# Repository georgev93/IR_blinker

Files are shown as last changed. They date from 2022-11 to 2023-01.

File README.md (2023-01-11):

# IR Blinker

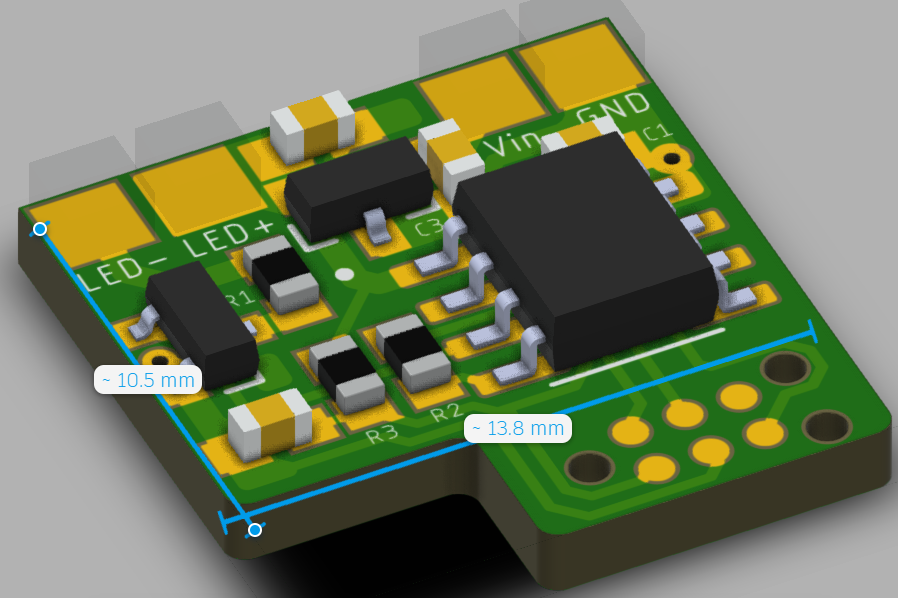
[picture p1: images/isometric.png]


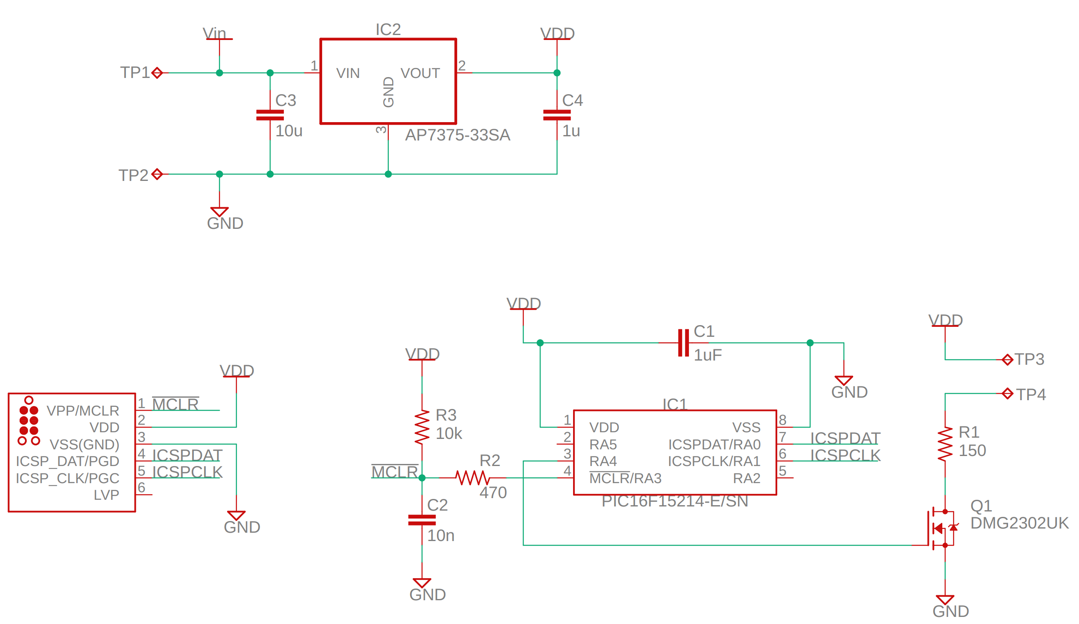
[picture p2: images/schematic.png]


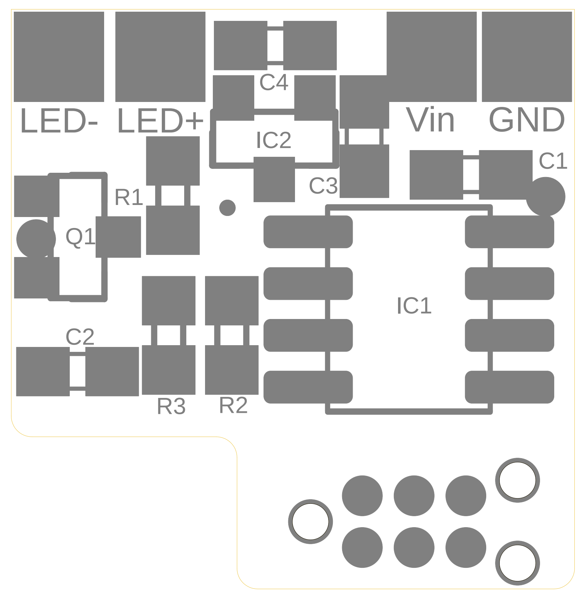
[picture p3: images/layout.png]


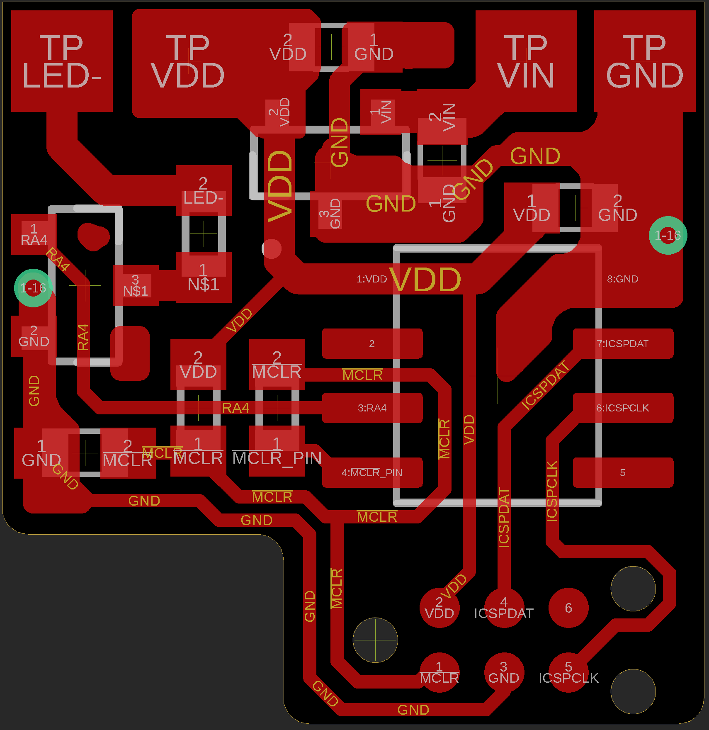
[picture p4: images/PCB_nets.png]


## Programming Connection

The programming tab shown at the bottom of the rendering above (which can be cut off after flashing for minimal final board size!) can be connected to a PIC programmer (such as a PICkit or ICD) via a Tag-Connect cable. The Tag-Connect cable should be a 6-pin no-legs variant such as [this one](https://www.tag-connect.com/product/tc2030-pkt-nl-6-pin-no-legs-cable-for-microchip-pickit-3) that connects to a [PICkit 3](https://www.microchip.com/en-us/development-tool/pg164130). A [retention clip](https://www.tag-connect.com/product/tc2030-retaining-clip-board-3-pack) for the no-leg Tag-connect connector makes life very easy. Lastly, if you lose your retention clips, you might want to invest in a [state-of-the-art-and-absolutely-not-just-a-paperclip retention clip holder](https://www.tag-connect.com/product/tc20x0-cliphanger).

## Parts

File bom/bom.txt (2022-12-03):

Part     Value            Package       Digikey P/N                     Mouser P/N

C1, C4   1uF              C0603         587-3305-1-ND                   963-EMK107B7105KAHT          
C2       10n              C0603         445-1311-1-ND                   810-C1608X7R1H103K
C3       10u              C0603         490-18214-1-ND                  81-GRM188R61E106KA3D
IC1      PIC16F15214-E/SN SOIC-8        150-PIC16F15214-I/SN-ND         (Out of stock)
IC2      AP7375-33SA      SOT23         (Out of stock)                  AP7375-33SA-7
Q1       DMG2302UK        SOT23         DMG2302UK-7DICT-ND              621-DMG2302UK-7
R1       150              R0603         13-RC0603FR-13150RLCT-ND        603-RC0603FR-13150RL
R2       470              R0603         13-RC0603FR-10470RLCT-ND        603-RC0603FR-10470RL
R3       10k              R0603         13-RC0603FR-1310KLCT-ND         603-RC0603FR-1310KL

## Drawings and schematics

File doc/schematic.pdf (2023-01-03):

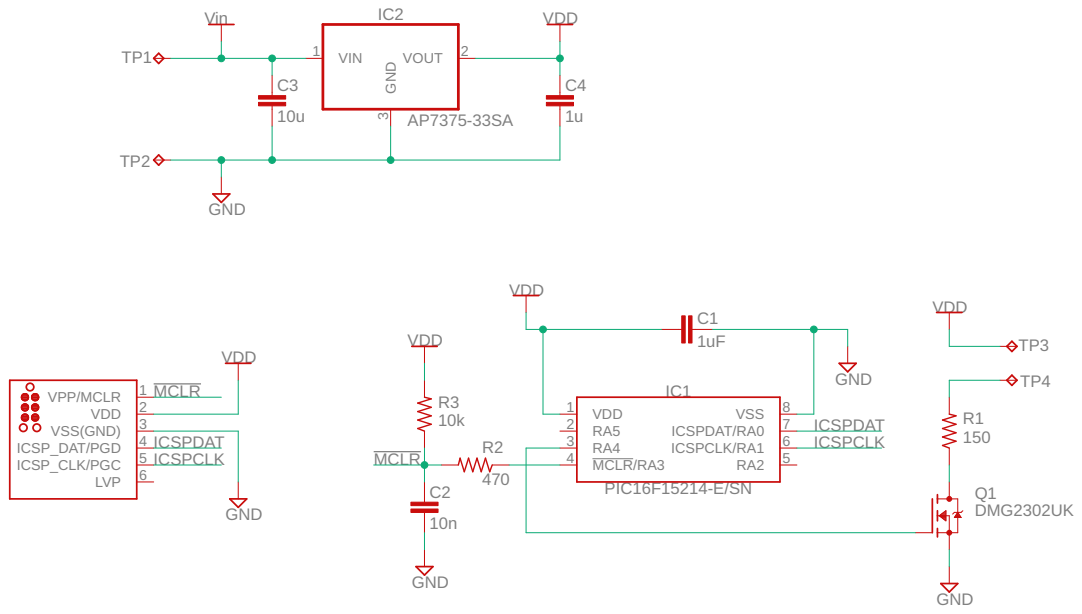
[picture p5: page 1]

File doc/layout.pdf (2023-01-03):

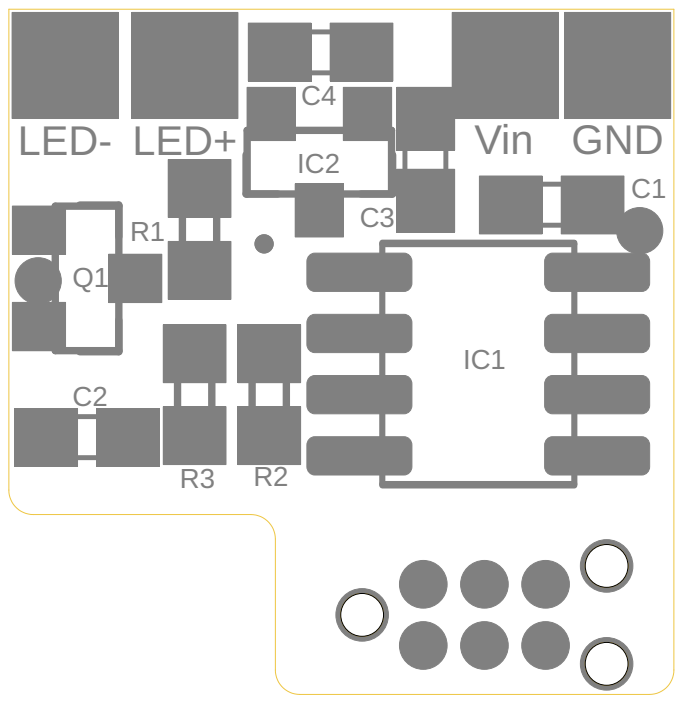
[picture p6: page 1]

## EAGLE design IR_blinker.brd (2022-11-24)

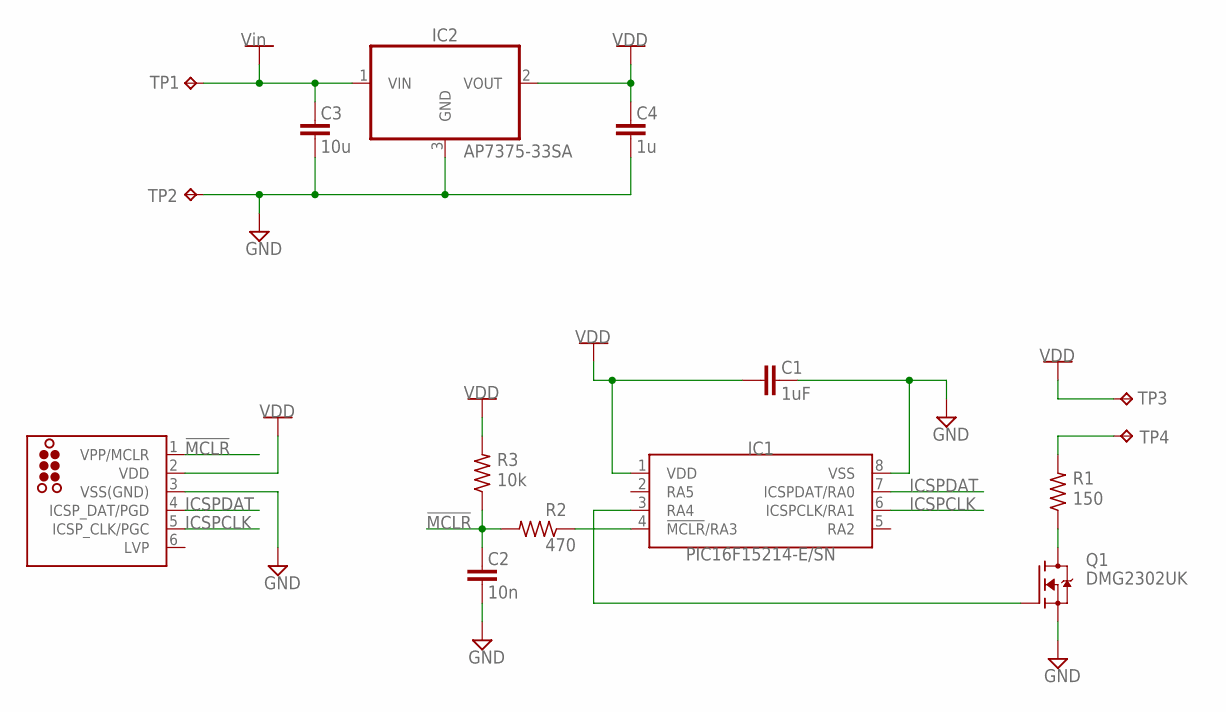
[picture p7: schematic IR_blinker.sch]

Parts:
C1: 1uF; C0603
C2: 10n; C0603
C3: 10u; C0603
C4: 1u; C0603
IC1: PIC16F15214-E/SN; SOIC-8
IC2: AP7375-33SA; SOT23
J1: TC2030-MCP-NL
Q1: DMG2302UK; SOT23
R1: 150; R0603
R2: 470; R0603
R3: 10k; R0603
TP1, TP2, TP3, TP4: TPTP20SQ; TP20SQ

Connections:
!MCLR: C2.2, J1.1 (VPP/MCLR), R2.2, R3.1
GND: C1.2, C2.1, C3.1, C4.1, IC1.8 (VSS), IC2.3 (GND), J1.3 (VSS(GND)), Q1.2 (S), TP2.TP
ICSPCLK: IC1.6 (ICSPCLK/RA1), J1.5 (ICSP_CLK/PGC)
ICSPDAT: IC1.7 (ICSPDAT/RA0), J1.4 (ICSP_DAT/PGD)
LED_RETURN: R1.2, TP4.TP
unnamed: Q1.3 (D), R1.1
unnamed: IC1.3 (RA4), Q1.1 (G)
unnamed: IC1.4 (!MCLR!/RA3), R2.1
VDD: C1.1, C4.2, IC1.1 (VDD), IC2.2 (VOUT), J1.2 (VDD), R3.2, TP3.TP
VIN: C3.2, IC2.1 (VIN), TP1.TP

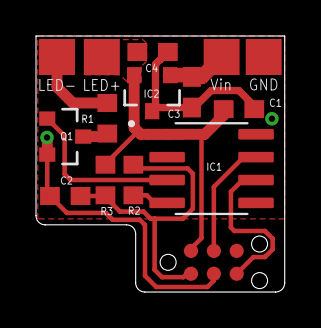
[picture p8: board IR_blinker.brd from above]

Board: 2 copper layers, 13.8 x 14.2 mm, 15 parts (0 on the bottom side), 10 nets.

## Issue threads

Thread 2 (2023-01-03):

Setting the current for the IR LED

georgev93, 2023-01-03:
So @emailing-files-is-still-better, not knowing what IR LED you're using for this bad boy I wasn't able to exactly dial in the current we want. Therefore, R1 is at 150 Ohms, which works well for a surface mount LED I picked out before I switched it to an off-board IR LED. Once you know your IR LED, you'll want to set the current appropriately (although 150 ohms might do you just fine).

### Step 1: Pick luminosity

If you have the datasheet, there should be a graph that correlates current to luminosity (or radiant intensity, lux, brightness, etc.). Like this one for the [TSAL6100](https://components101.com/sites/default/files/component_datasheet/IR%20LED%20datasheet.pdf):

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

(Note the nearly linear relationship between log(current) and log(radiant intensity))

Pick your value. Better yet, if you have a lab power supply, drive a constant current through the LED, then pick your favorite luminosity. You can set a power supply in "constant current" mode by setting your limit to something like 10mA, then set your voltage to something that is higher than what you expect the forward voltage drop to be (like 5V). When you connect the LED to the power supply, it will only let 10mA through, so it will drop the voltage until it achieves that current (constant current mode).

 One way or another, this value determines the current that we want to run through the LED. You can likely use your phone camera to compare brightness of LEDs (although if you're comparing to a 50% duty cycle LED, it'll show up half as bright!)

### Step 2: Determine Your Current

Use either the graph from the datasheet or your experimental results to choose the current you want to drive your LED at.

### Step 3: Determine the Forward Voltage of that LED at the Given Current

The LED will drop a certain voltage across it based on the current you push through. If you have the datasheet on hand, there should be a graph with this information. Like this one:

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

(Note the higher the current, the higher the forward voltage drop)

If you don't have the datasheet on hand, look at the power supply when you're pushing your chosen current through. The power supply will be making a voltage equal to the forward voltage drop of the LED.

### Step 4: Determine the value of R1

Finally! What we came here to do. The R1/LED combo is being supplied with a regulated 3.3V. Subtract out the forward voltage drop of the LED from 3.3V, and you'll be left with the voltage drop across the resistor. Then use Ohm's Law (`V = I * R`) to find the value of your resistor.

Example: You want your current to be 10mA, which means the LED has a forward voltage drop of 1.2V. You have 2.1V to drop over R1 (`3.3V - 1.2V = 2.1V`). Your resistor that you need is 210 Ohms (`2.1V = 0.010A * R`, `R = 2.1V / 0.010A = 210 Ohms`).

I know a place where you could steal an 0603 resistor or two...

georgev93, 2023-01-03:
Alternatively, you could always wing it with 150 ohms for R1. Just know that could be kind of a pain in the ass to unsolder that 0603 resistor and replace it with something else when the rest of the board is already populated

georgev93, 2023-01-03:
And try to keep the current under 100 mA if you can. Much higher and we risk overheating the regulator

emailing-files-is-still-better, 2023-01-03:
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

So this is what I currently have on hand, and as close to a data sheet as possible haha. Winging it was my plan for the first board, I mean how much can LEDs really vary 😉

georgev93, 2023-01-03:
From the small amount of English in that, there's a few specs that would indicate that we're looking at an LED, but it also says "receiver" a few times. Is this an LED or a photodiode?

emailing-files-is-still-better, 2023-01-04:
Haha. Both are sold from the same page, wasn't sure if there was led data mixed in there as well. https://s.lazada.co.th/s.iLXsA

georgev93, 2023-01-04:
If that's describing the LED as having a forward voltage of 1.1-1.4V, then a 150 ohm R1 would set the current somewhere between 12.7-14.7mA. That's likely a very comfortable point to operate at given that it seems to list the max current as 30mA. Just know that you can nearly double the brightness if you need to by decreasing R1.

emailing-files-is-still-better, 2023-01-05:
Well that gives me enough confidence to at least try one, brightness would just increase range right? Or would it also increase reliability at high passing speeds?

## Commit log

2022-11-20 First swipe (no regulator)
    [IR_blinker.brd, IR_blinker.sch]
2022-11-24 Linear Regulator added. Passives added to MCLR.
    [IR_blinker.brd, IR_blinker.sch]
2022-12-03 Adding BOM, readme, and cam file
2023-01-03 Adding schematic and layout pdfs (and images to the README)

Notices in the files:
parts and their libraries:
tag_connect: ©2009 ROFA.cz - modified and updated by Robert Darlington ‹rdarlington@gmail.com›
